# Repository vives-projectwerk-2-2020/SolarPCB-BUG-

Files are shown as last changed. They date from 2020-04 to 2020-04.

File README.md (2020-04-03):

# SolarPCB-BUG-
Full project with schematic, board and datasheets of the solar consumption board

In deze repo zit alles wat ik heb gebruikt voor mijn pcb. De schema's van ieder develop bordje en mijn eigen pcb.
Ook telkens de datasheet van mijn gebruikte IC's

## -BUG-

het probleem waar ik mee zit.
Als ik het systeem laat werken, zonder dat ik er een batterij op aansluit, is het stabiel en blijft het werken.
Vanaf ik er een batterij op aansluit, dan valt na 2 a 3 min de stroom weg en valt de laadspanning van 4,2V --> 2,7V.

De laadstroom die ik kan meten gedurdende de 2 a 3 werkende minuten is 3,7 a 3,9 mA met een laadspanning van 4,2V.

Als ik de PCB eens los maak van de zonnepanneel en terug aansluit, dan werkt de PCB terug voor enkele minuten en valt daarna terug uit.
Ook als ik de capaciteit ontlaadt, werkt het terug, maar dan kom ik gewoon terug in de start postitie te staan, waardoor het logisch is dat hij terug werkt.

Het is IC MCP73871 die uitvalt. Op zijn uitgang (Vbat) komt er dan een spanning van 2.7V en in werkende toestand staat daar een spanning van 4,2V, alle IC's erna, zijn afhankelijk van deze IC, dus de MCP73871 kan maximaal 2.7V meer leveren aan de batterij, wat te weinig is.

Eerst dacht ik dat de ingangsspanning te hoog was voor de IC, waardoor hij uitschakelde, of sneuvelde omdat mijn zonnepanneel 7V leverde en er max 6V op de ingang van de IC mocht komen. Ik heb er een 7805 tussen geplaatst, maar tevergeefs.

mochten er nog zaken niet duidelijk zijn over het probleem, mag je mij altijd een mailtje sturen, of op teams een DM sturen.

Alvast bedankt!

Tom Van Hove

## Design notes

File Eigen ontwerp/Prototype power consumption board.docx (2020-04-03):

# Prototype power consumption board

# Schematic

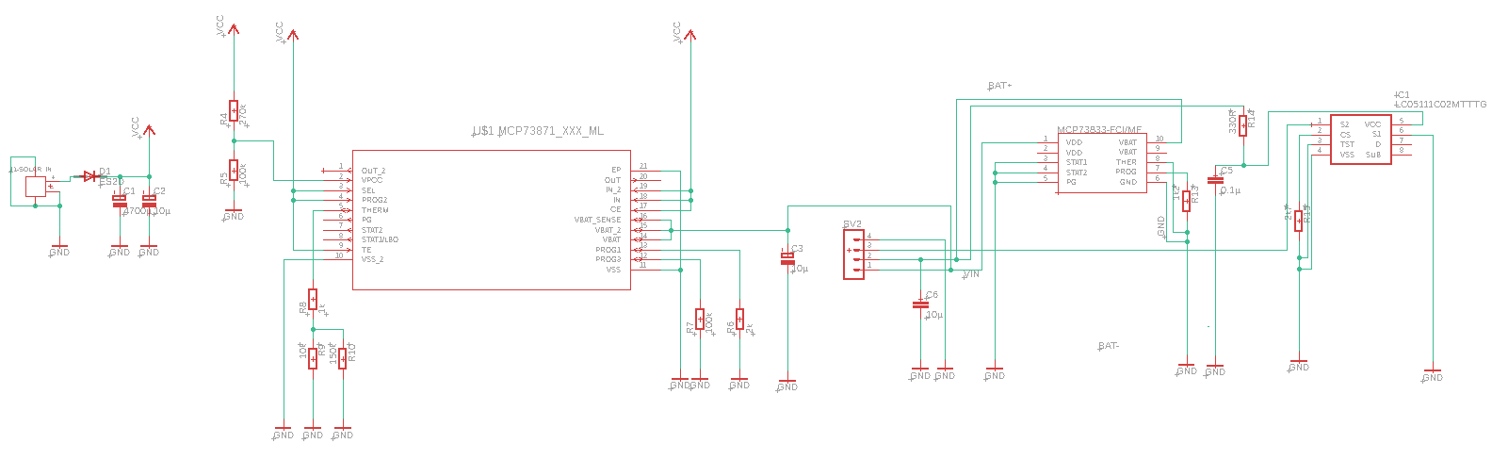
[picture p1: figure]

# Board

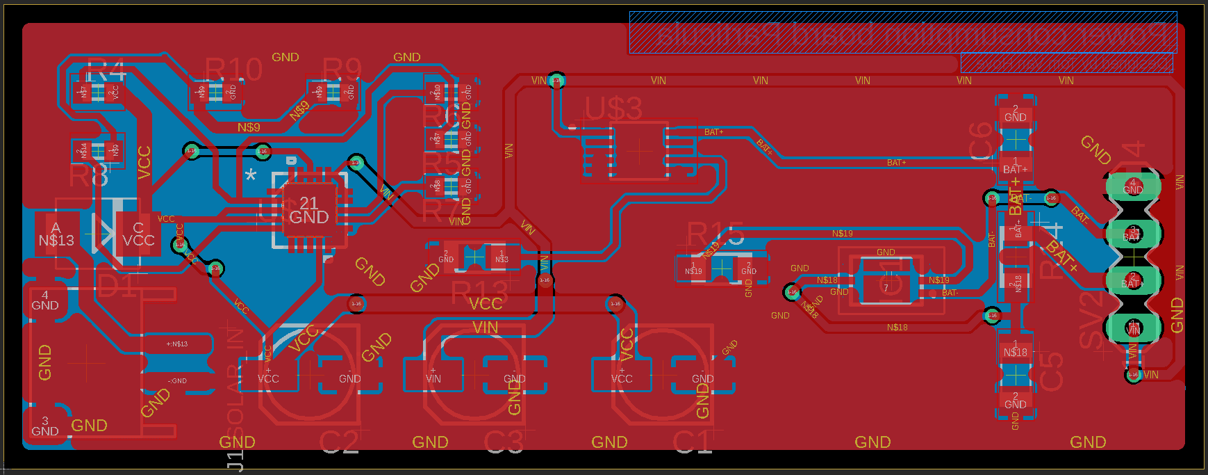
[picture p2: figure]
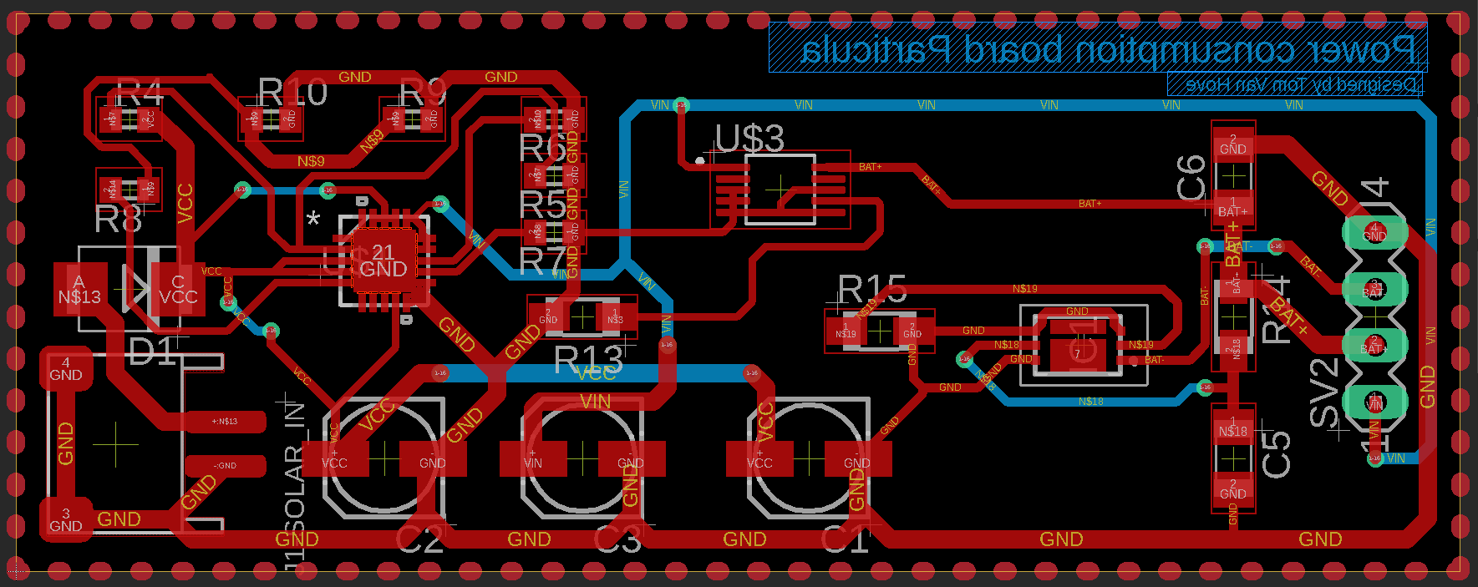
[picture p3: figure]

# Partlist FARNELL

Part | Value | FARNELL NR
C1 | 4700Âµ | 2346507
C2 | 10Âµ | 9697012
C3 | 10Âµ | 9697012
C5 | 0.1Âµ | 2211074
C6 | 10Âµ | 1907353
D1 | ES2D | 1467491
IC1 | LC05111C02MTTTG | 2728216
J1-SOLAR_IN
R4 | 270k | 2447313
R5 | 100k | 1692517
R6 | 2k | 2447319
R7 | 100k | 1692517
R8 | 1k | 9238484
R9 | 10k | 2861870
R10 | 150k | 2447254
R13 | 1k2 | 3254959
R14 | 330R | 3254970
R15 | 2k7 | 3254908
SV2 | | 1667510
U$1 | MCP73871_XXX_ML | 1642489
U$3 | MCP73833-FCI/MF | 1605576

# Recommandations

## PCB order

The ordering of the PCBs went very well. JLCPCB is an good site with fast shipping. The quality of them are very nice!

## Component order

We worked with Farnell because their fast shipping. Everything went well, all components are in stock and they were delivered very soon. But in multiple packets.

## Soldering

The soldering went great. We used only SMD. With the soldering station of VIVES it went very good! We used very small components because of available space on our PCB and we need to fit 3 PCBs in 1 single box with batteries.

I can make my PCB more smaller and that’s the next step after testing and debugging.

One mistake we made with the component order, we didn’t order an FLUX CLEANER so our PCB is a bit dirty right now. The final PCB will be clean.

## Testing

I tested the PCB only with a solarpanell and without batteries. And I got a voltage measure of 4.2V what is very nice!

After that step I loaded some batteries and the PCB stop charging when the batteries are 3.7V loaded. I’m not sure that that would be enough for feeding the NUCLEO and other hardware. Maybe I can place 2 batteries serial, but my pcb won’t work anymore. I can place them parallel too, for more capacity.

After charging the batteries, I discharged them with an ventilator (just a consumer, it could be anything). The ventilator worked 22 hours, non stop.

After this I recharged 1 battery …

TODO

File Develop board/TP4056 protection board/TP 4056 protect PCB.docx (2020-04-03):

# TP 4056 - protect PCB

# Specificaties

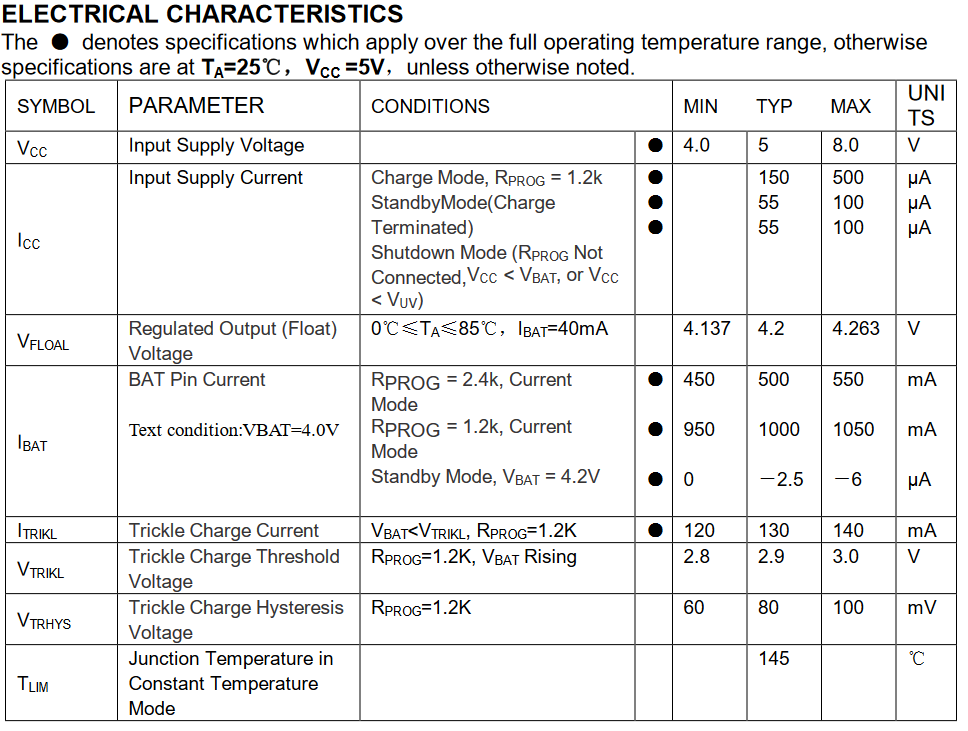
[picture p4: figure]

# Doel

Bescherming batterij tegen overspanning. Als de batterij vol geladen is, dan zal deze schakeling de kring onderbreken.

# Werking

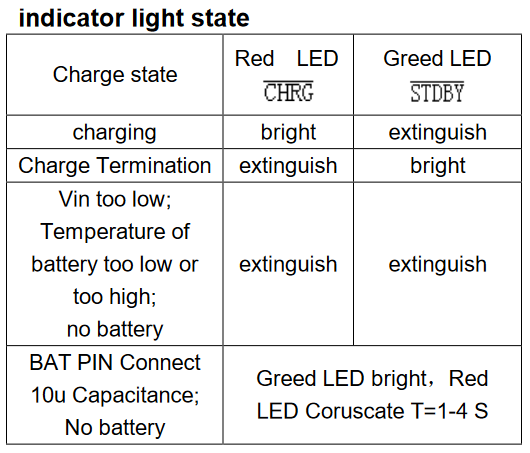
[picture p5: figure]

Als de batterij aan het opladen is, dan zal de rode led gaan branden op de PCB. Als de batterij volgeladen is dan gaat de groene led oplichten.

Stel er hangt geen batterij aan, of de ingangsspanning is te laag, temperatuur te hoog of te laag is.

Bij het opladen met het zonnepanneel, hebben we een laadstroom van rond de 50mA. Kiezen we voor een USB gevoede lading, spreken we over een laadstroom van rond de 150mA. Resultaat, via USB zal de batterij veel sneller geladen kunnen worden.

Als de spanning van de batterij stijgt, dan zal de laadstroom dalen, tot op 0, waarbij de groene led dan gaat branden.

# Schematische voorstelling

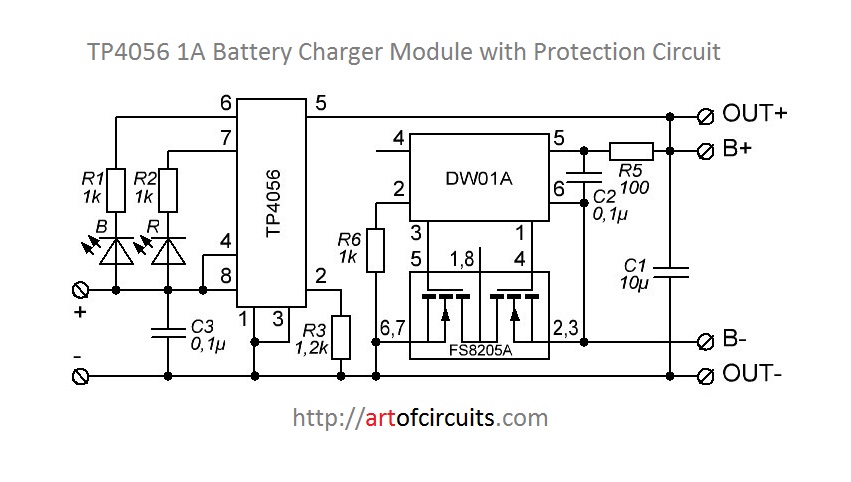
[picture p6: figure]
Schema
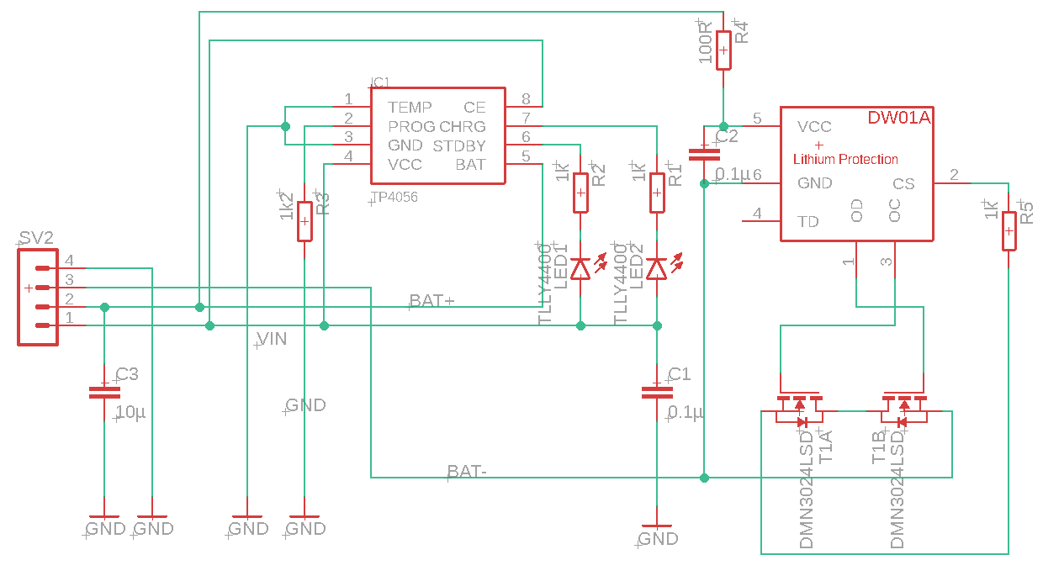
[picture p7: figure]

# Board

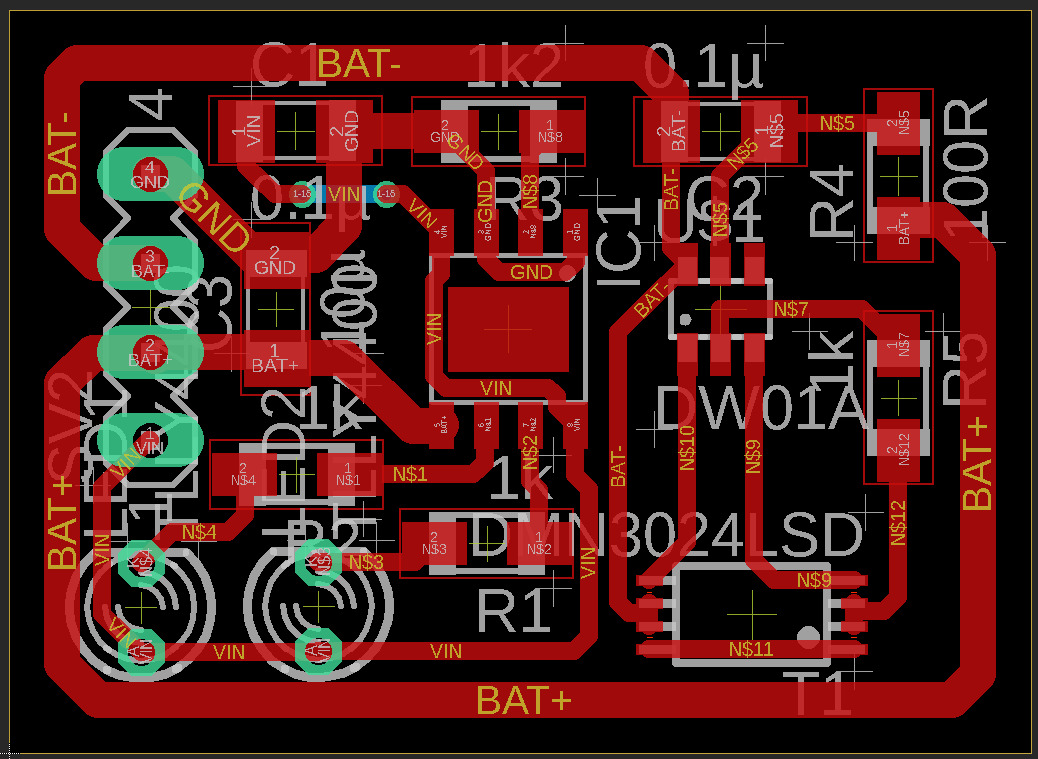
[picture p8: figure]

## DW01A

https://www.ic-fortune.com/upload/Download/DW01x-DS-17_EN_53550.pdf

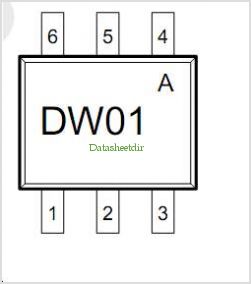
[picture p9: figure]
DW01A pinout,Pin out

## TP4056

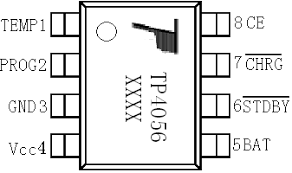
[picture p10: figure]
C:\Users\Tom\AppData\Local\Microsoft\Windows\INetCache\Content.MSO\A78E72FA.tmp

## FS8205A

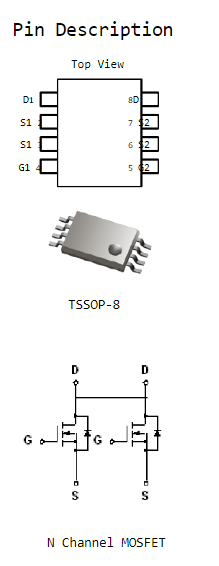
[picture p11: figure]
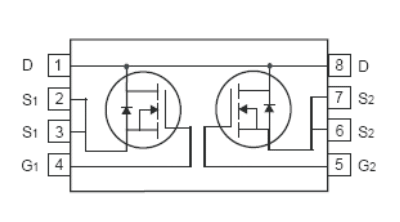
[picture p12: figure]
Afbeeldingsresultaat voor 8205a pinout
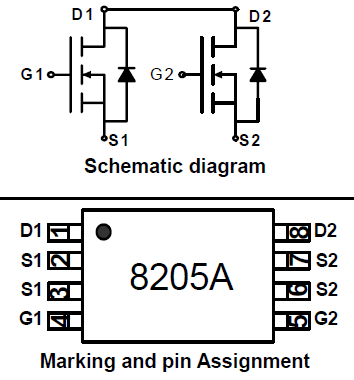
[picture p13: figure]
Afbeeldingsresultaat voor 8205a pinout

# Aansluiting

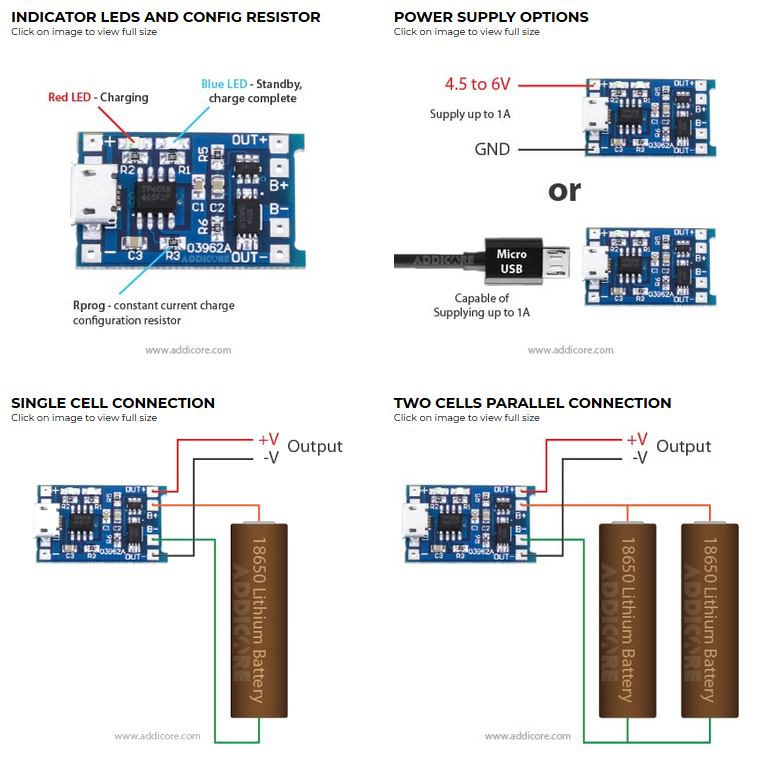
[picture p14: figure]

# Interessante links

https://dlnmh9ip6v2uc.cloudfront.net/datasheets/Prototyping/TP4056.pdf

https://www.makerlab-electronics.com/product/tp4056-5v-1a-lithium-battery-charging-with-protection-micro-usb/

https://www.addicore.com/TP4056-Charger-and-Protection-Module-p/ad310.htm

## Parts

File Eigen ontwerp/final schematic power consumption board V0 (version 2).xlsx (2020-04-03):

Part | Value | Device | Package | Description
C1 | 4700Âµ | CPOL-EU153CLV-0505 | 153CLV-0505 | POLARIZED CAPACITOR, European symbol | 2346507 | 3 | https://be.farnell.com/rubycon/16pk4700mefc12-5x25/cap-4700-f-16v-20/dp/2346507
C2 | 10Âµ | CPOL-EU153CLV-0505 | 153CLV-0505 | POLARIZED CAPACITOR, European symbol | 9697012 |  | https://be.farnell.com/panasonic/eee1va100sr/cap-10-f-35v-radial-smd/dp/9697012
C3 | 10Âµ | CPOL-EU153CLV-0505 | 153CLV-0505 | POLARIZED CAPACITOR, European symbol | 9697012 |  | https://be.farnell.com/panasonic/eee1va100sr/cap-10-f-35v-radial-smd/dp/9697012
C5 | 0.1Âµ | C-EUC1206 | C1206 | CAPACITOR, European symbol | 2211074 |  | https://be.farnell.com/tdk/cga5l2c0g1h104j160aa/cap-0-1-f-50v-5-c0g-np0-1206/dp/2211074
C6 | 10Âµ | C-EUC1206 | C1206 | CAPACITOR, European symbol | 1907353 |  | https://be.farnell.com/tdk/c3216x7r1c106k160ac/cap-10-f-16v-10-x7r-1206/dp/1907353
D1 | ES2D | ES2D | SMB | DIODE | 1467491 |  | https://be.farnell.com/on-semiconductor/es2d/diode-fast-2a-200v-smd-do-214/dp/1467491?st=ES2D
IC1 | LC05111C02MTTTG | LC05111C02MTTTG | LC05111C02MTTTG | Battery Management 1 CELL LIB PROTECTION IC | 2728216 |  | https://be.farnell.com/on-semiconductor/lc05111c02mtttg/over-current-protector-li-ion/dp/2728216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
J1-SOLAR_IN |  | CONN-HEADER-SMD-PH-SIDE-(2P-2.0MM) | HW2-SMD-2.0-90D | 320110026
R4 | 270k | R-EU_R0603 | R0603 | RESISTOR, European symbol | 2447313 |  | https://be.farnell.com/multicomp/mcwr06x2703ftl/res-270k-1-0-1w-thick-film/dp/2447313
R5 | 100k | R-EU_R0603 | R0603 | RESISTOR, European symbol | 1692517 |  | https://be.farnell.com/vishay/crcw0603100kjnea/res-100k-5-0-1w-0603-thick-film/dp/1692517
R6 | 2k | R-EU_R0603 | R0603 | RESISTOR, European symbol | 2447319 |  | https://be.farnell.com/multicomp/mcwr06x2001ftl/res-2k-1-0-1w-0603-thick-film/dp/2447319
R7 | 100k | R-EU_R0603 | R0603 | RESISTOR, European symbol | 1692517 |  | https://be.farnell.com/vishay/crcw0603100kjnea/res-100k-5-0-1w-0603-thick-film/dp/1692517
R8 | 1k | R-EU_R0603 | R0603 | RESISTOR, European symbol | 9238484 |  | https://be.farnell.com/yageo/rc0603fr-071kl/res-1k-1-0-1w-0603-thick-film/dp/9238484
R9 | 10k | R-EU_R0603 | R0603 | RESISTOR, European symbol | 2861870 |  | https://be.farnell.com/te-connectivity/crgcq0603j10k/res-10k-5-0603-thick-film/dp/2861870
R10 | 150k | R-EU_R0603 | R0603 | RESISTOR, European symbol | 2447254 |  | https://be.farnell.com/multicomp/mcwr06x1503ftl/res-150k-1-0-1w-thick-film/dp/2447254
R13 | 1k2 | R-EU_R1206W | R1206W | RESISTOR, European symbol | 3254959 |  | https://be.farnell.com/rohm/ltr18ezpj122/res-1k2-5-0-75w-1206-thick-film/dp/3254959
R14 | 330R | R-EU_R1206W | R1206W | RESISTOR, European symbol | 3254970 |  | https://be.farnell.com/rohm/ltr18ezpj331/res-330r-5-0-75w-1206-thick-film/dp/3254970
R15 | 2k7 | R-EU_R1206W | R1206W | RESISTOR, European symbol | 3254908 |  | https://be.farnell.com/rohm/ltr18ezpf2701/res-2k7-1-0-75w-1206-thick-film/dp/3254908
SV2 |  | MA04-1 | MA04-1 | PIN HEADER | 1667510 |  | https://be.farnell.com/samtec/ces-104-01-t-s/receptacle-2-54mm-single-4way/dp/1667510
U$1 | MCP73871_XXX_ML | MCP73871_XXX_ML | QFN20_4X4MC |  | 1642489 |  | https://be.farnell.com/microchip/mcp73871-2cci-ml/ic-battery-management-cont-qfn20/dp/1642489?st=MCP73871
U$3 | MCP73833-FCI/MF | MCP73833-FCI/MF | SOP50P490X110-10N |  | 1605576 |  | https://be.farnell.com/microchip/mcp73833-fci-un/ic-charge-control-li-ion-1a-msop/dp/1605576?st=MCP73833

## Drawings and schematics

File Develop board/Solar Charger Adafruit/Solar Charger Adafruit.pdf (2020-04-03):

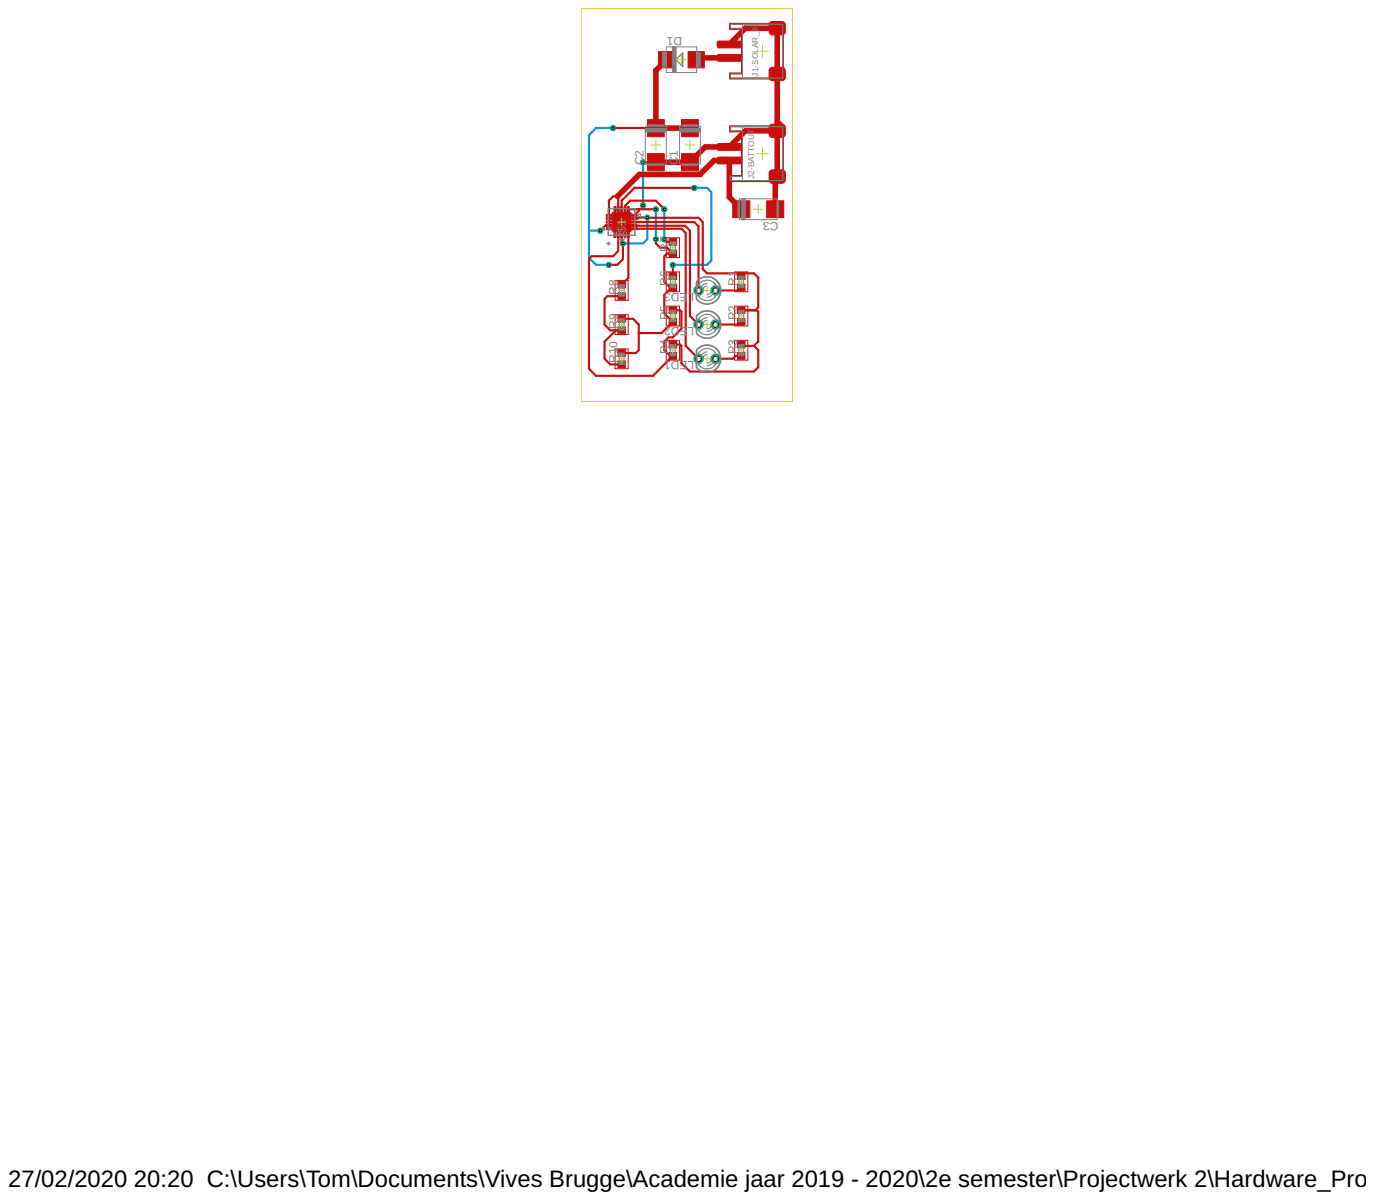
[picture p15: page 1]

27/02/2020 20:20 C:\Users\Tom\Documents\Vives Brugge\Academie jaar 2019 - 2020\2e semester\Projectwerk 2\Hardware_Prototype\Solar Charger Adafruit\Solar Charger Adafruit.brd

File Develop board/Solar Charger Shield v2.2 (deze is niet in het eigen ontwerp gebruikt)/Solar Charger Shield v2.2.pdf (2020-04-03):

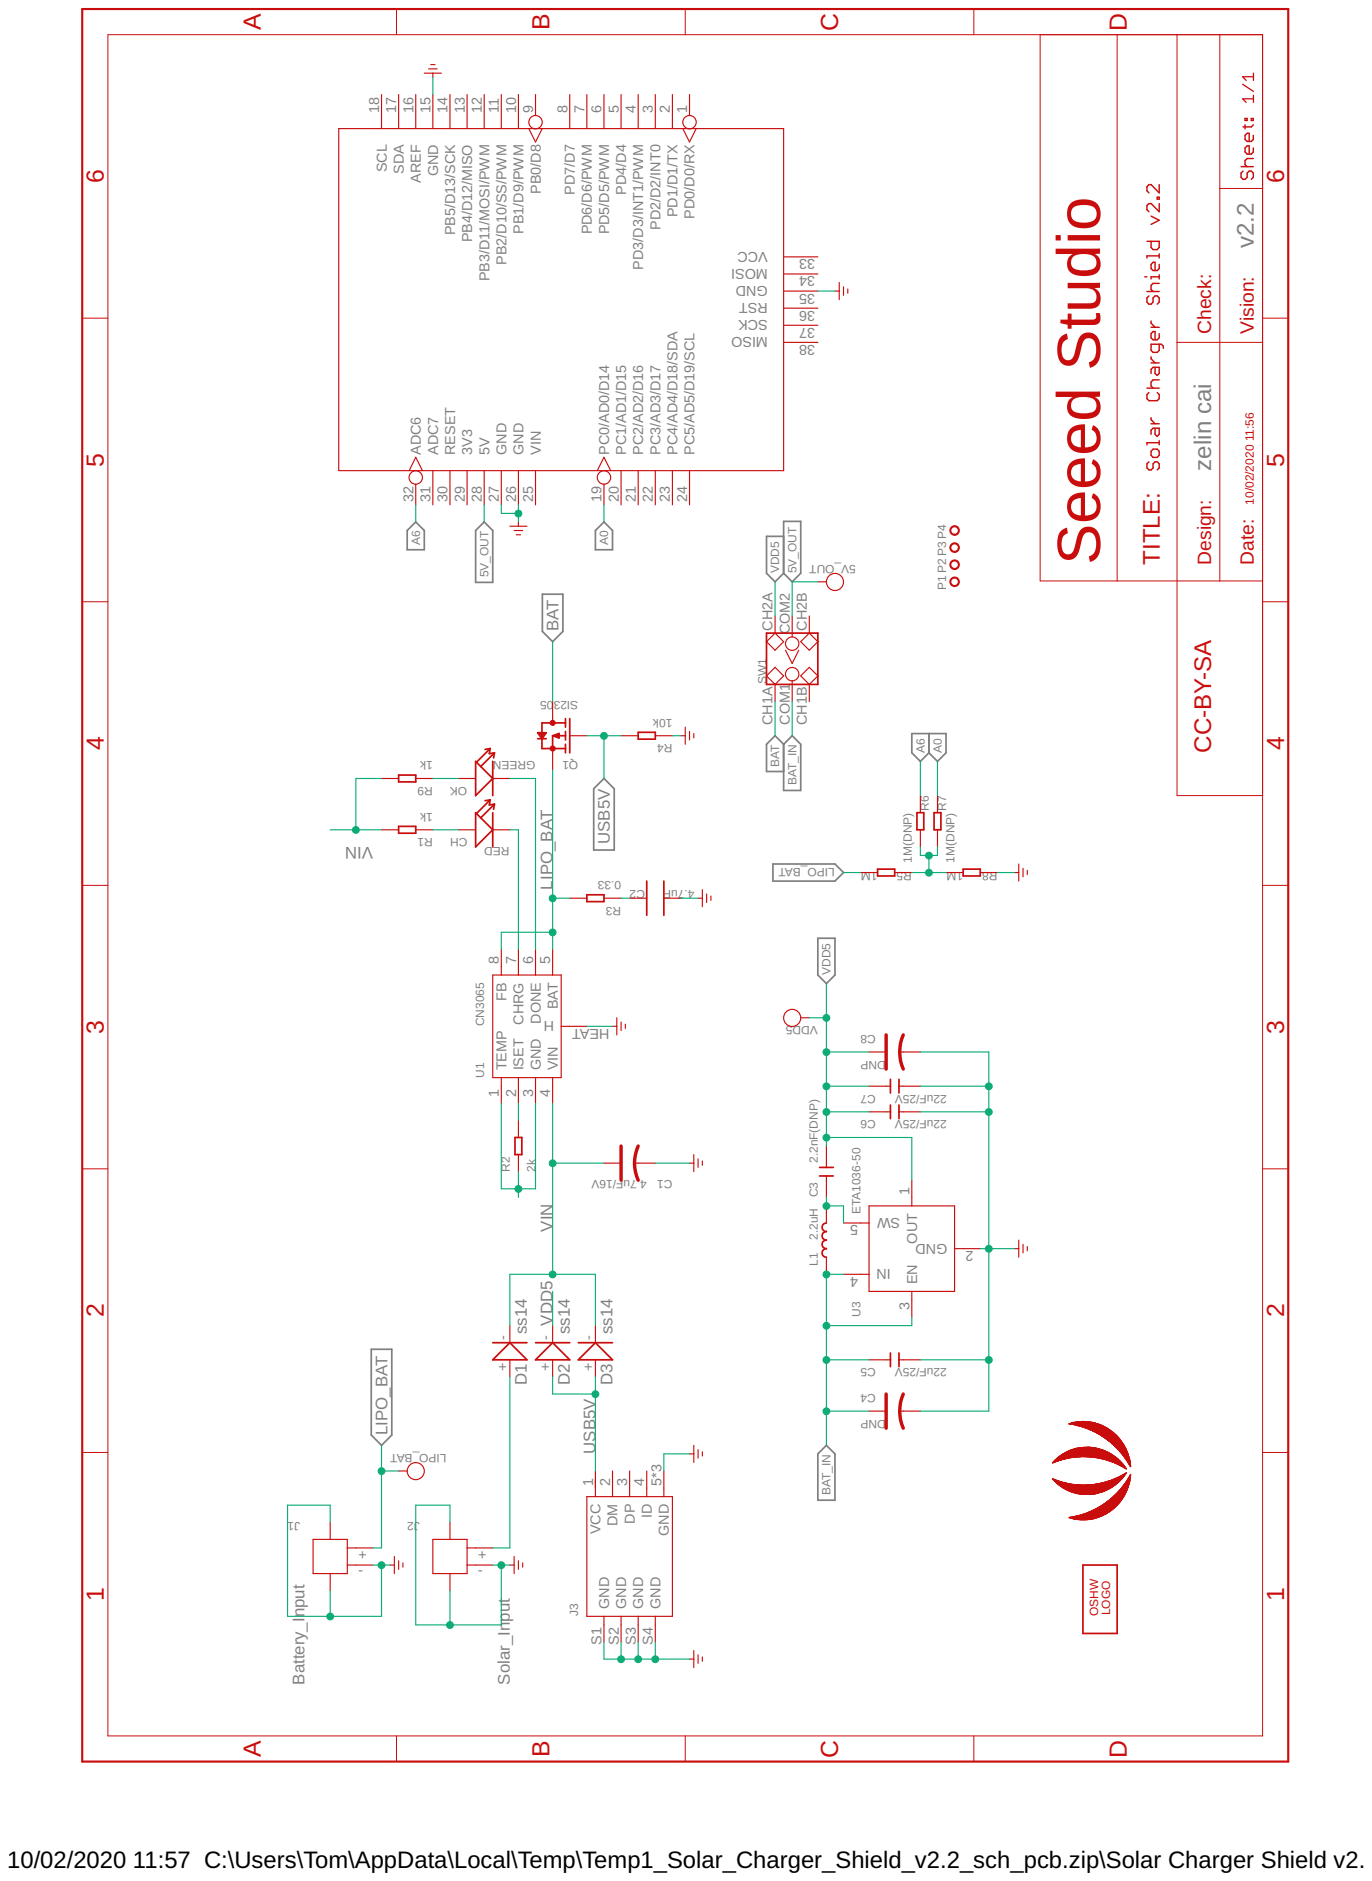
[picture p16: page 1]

TITLE: Design: Check: Date: Vision:

10/02/2020 11:57 C:\Users\Tom\AppData\Local\Temp\Temp1_Solar_Charger_Shield_v2.2_sch_pcb.zip\Solar Charger Shield v2.2.sch (Sheet: 1/1)

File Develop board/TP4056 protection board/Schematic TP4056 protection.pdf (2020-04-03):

# U3Vout 2

TP4056+protection | blob:https://easyeda.com/caab3f5a-f87a-41e1-b9f1-f607f42ea68e

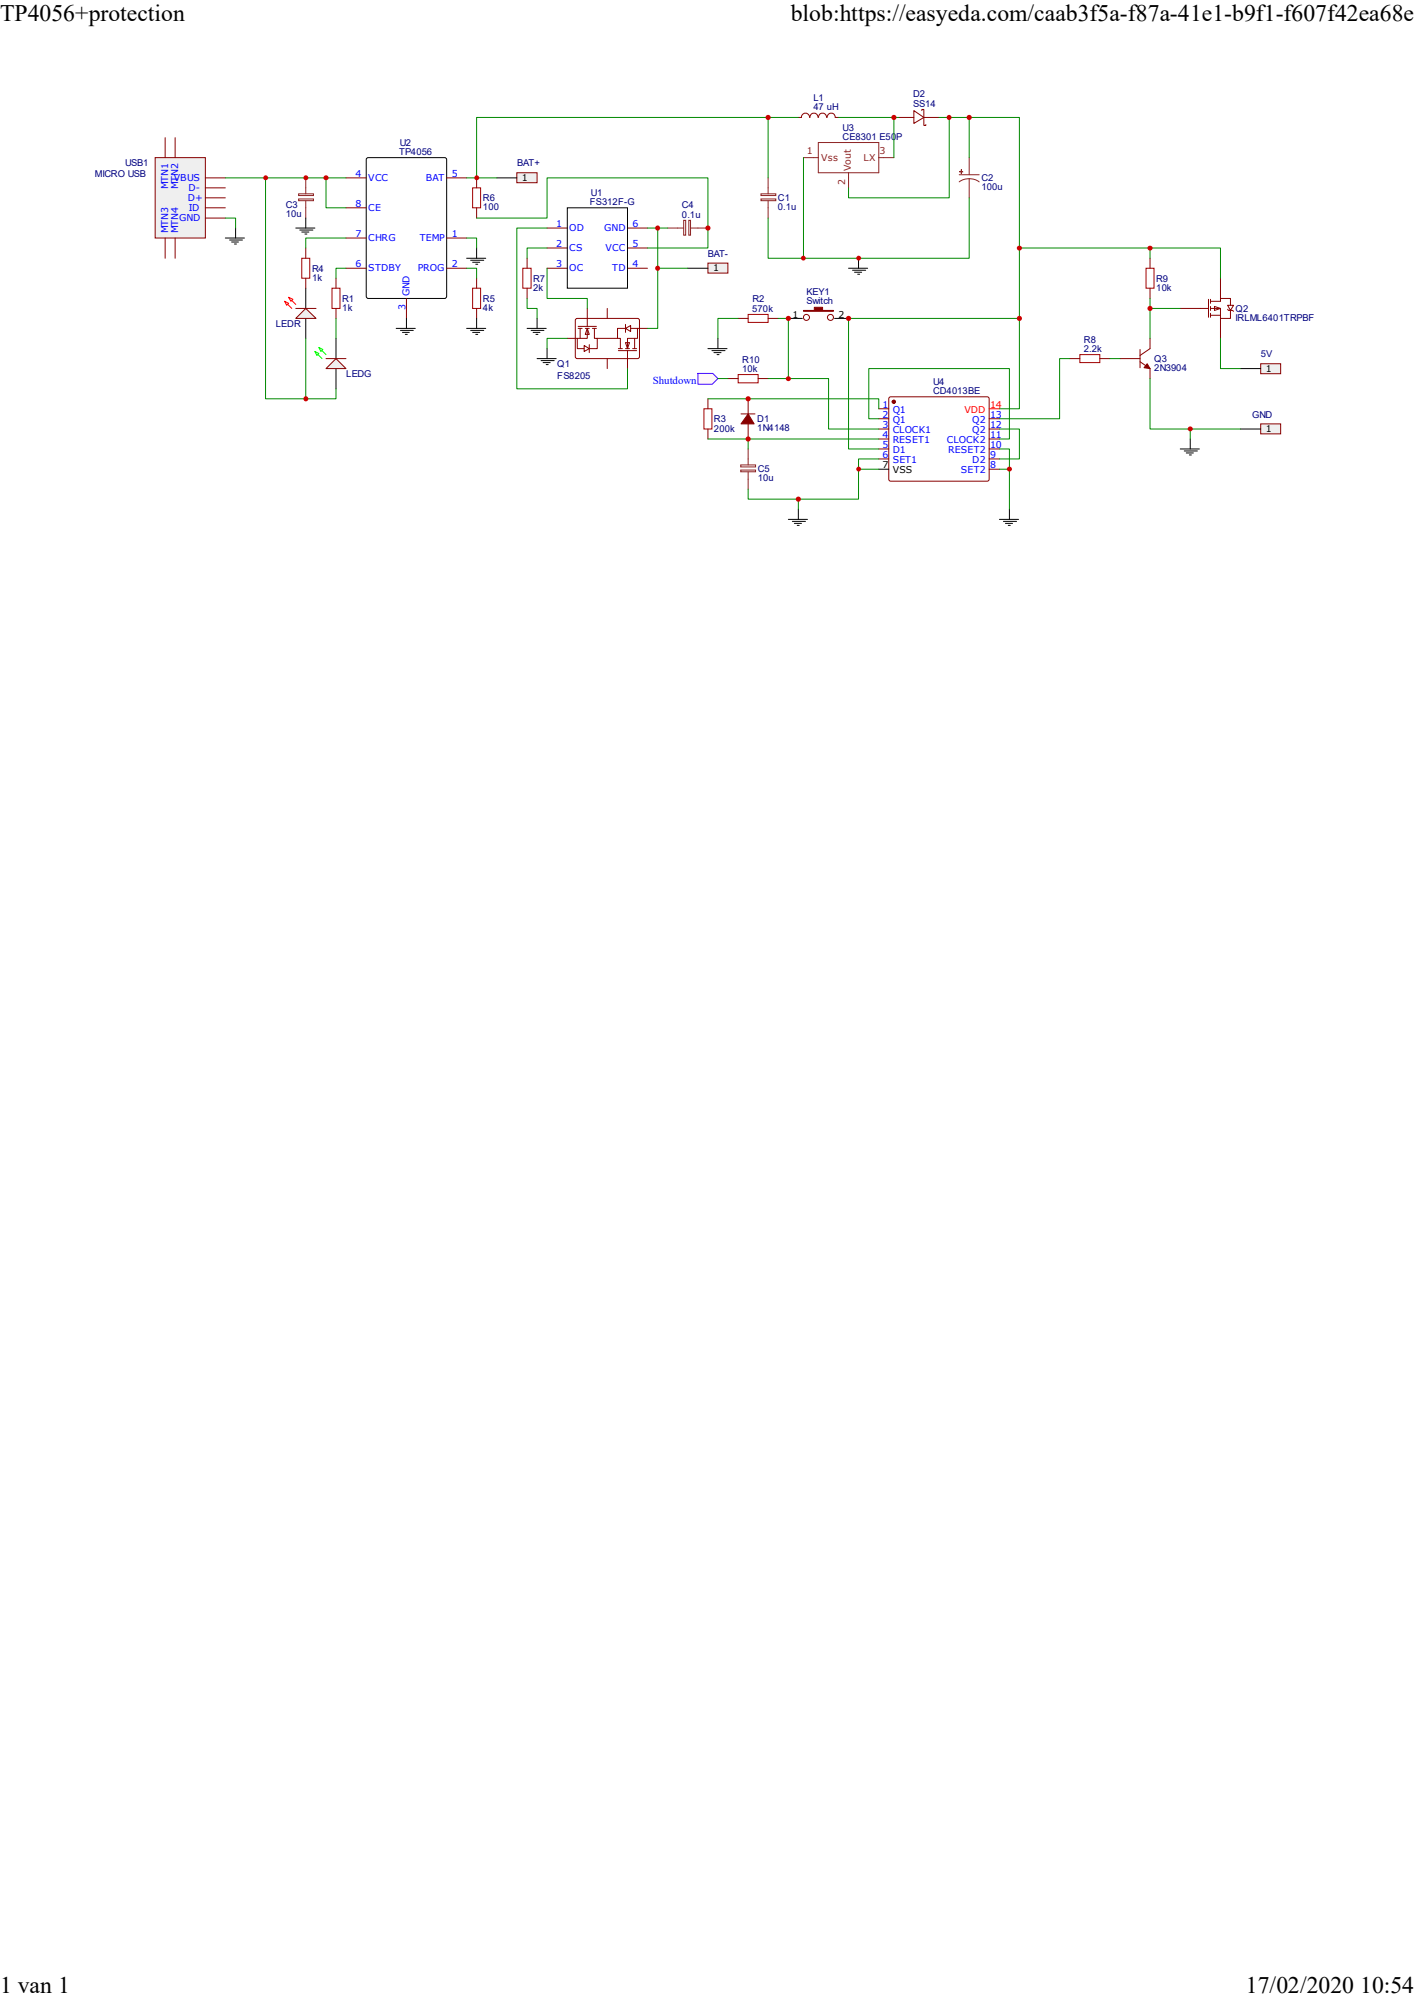
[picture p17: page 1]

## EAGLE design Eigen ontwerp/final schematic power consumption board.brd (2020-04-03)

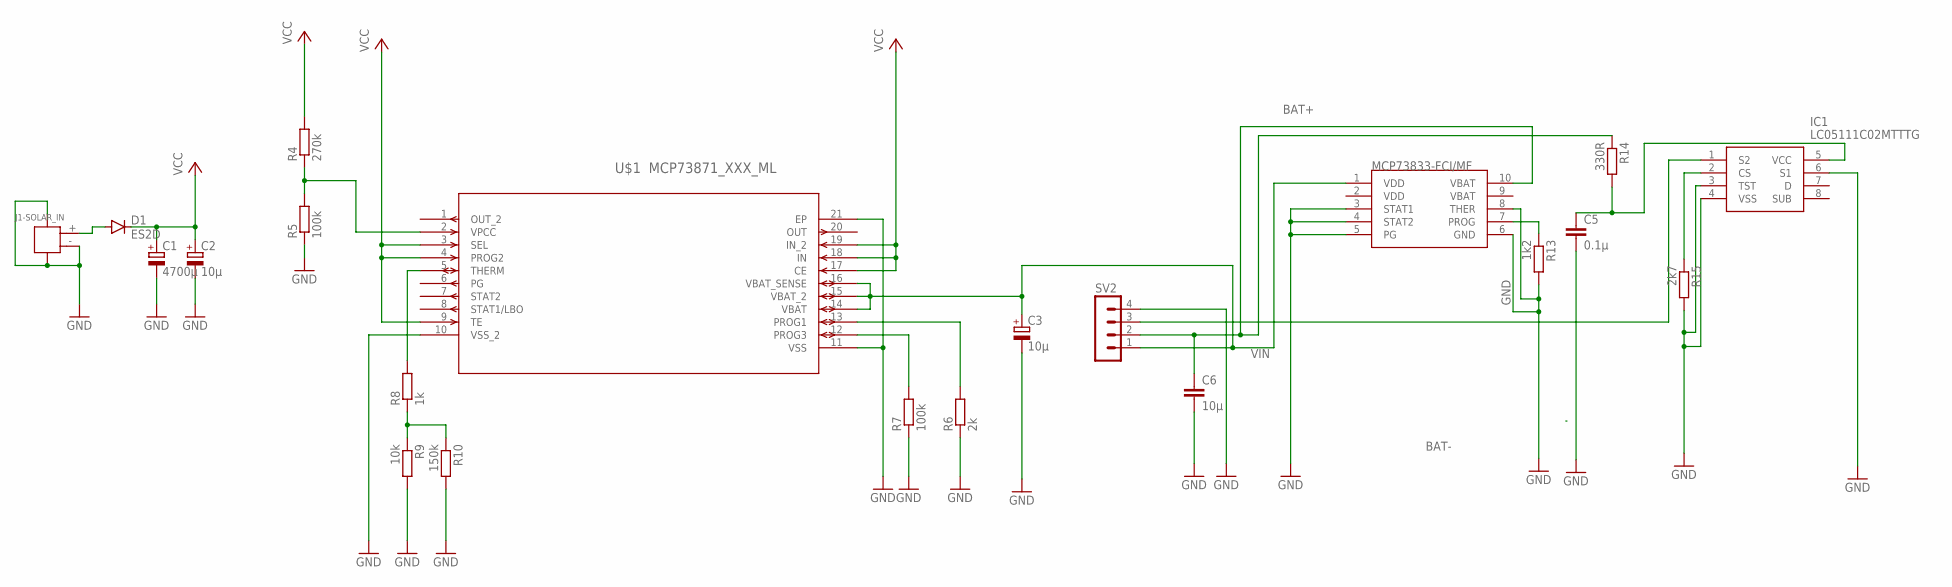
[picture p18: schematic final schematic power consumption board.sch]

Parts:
C1: 4700µ; 153CLV-0505
C2, C3: 10µ; 153CLV-0505
C5: 0.1µ; C1206
C6: 10µ; C1206
D1: ES2D; SMB
IC1: LC05111C02MTTTG
J1-SOLAR_IN: CONN-HEADER-SMD-PH-SIDE-(2P-2.0MM); HW2-SMD-2.0-90D
R4: 270k; R0603
R5, R7: 100k; R0603
R6: 2k; R0603
R8: 1k; R0603
R9: 10k; R0603
R10: 150k; R0603
R13: 1k2; R1206W
R14: 330R; R1206W
R15: 2k7; R1206W
SV2: MA04-1
U$1: MCP73871_XXX_ML; QFN20_4X4MC
U$3: MCP73833-FCI/MF; SOP50P490X110-10N

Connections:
BAT+: C6.1, R14.1, SV2.2, U$3.10 (VBAT)
BAT-: IC1.1 (S2), SV2.3
GND: C1.-, C2.-, C3.-, C5.2, C6.2, IC1.3 (TST), IC1.4 (VSS), IC1.6 (S1), J1-SOLAR_IN.3, J1-SOLAR_IN.4, J1-SOLAR_IN.- (2), R5.1, R6.1, R7.1, R9.2, R10.2, R13.2, R15.2, SV2.4, U$1.10 (VSS_2), U$1.11 (VSS), U$1.21 (EP), U$3.3 (STAT1), U$3.4 (STAT2), U$3.5 (PG), U$3.6 (GND), U$3.8 (THER)
unnamed: R13.1, U$3.7 (PROG)
unnamed: R4.1, R5.2, U$1.2 (VPCC)
unnamed: R7.2, U$1.12 (PROG3)
unnamed: R8.1, R9.1, R10.1
unnamed: R6.2, U$1.13 (PROG1)
unnamed: D1.A, J1-SOLAR_IN.+ (1)
unnamed: R8.2, U$1.5 (THERM)
unnamed: C5.1, IC1.5 (VCC), R14.2
unnamed: IC1.2 (CS), R15.1
VCC: C1.+, C2.+, D1.C, R4.2, U$1.3 (SEL), U$1.4 (PROG2), U$1.9 (TE), U$1.17 (CE), U$1.18 (IN), U$1.19 (IN_2)
VIN: C3.+, SV2.1, U$1.14 (VBAT), U$1.15 (VBAT_2), U$1.16 (VBAT_SENSE), U$3.1 (VDD)

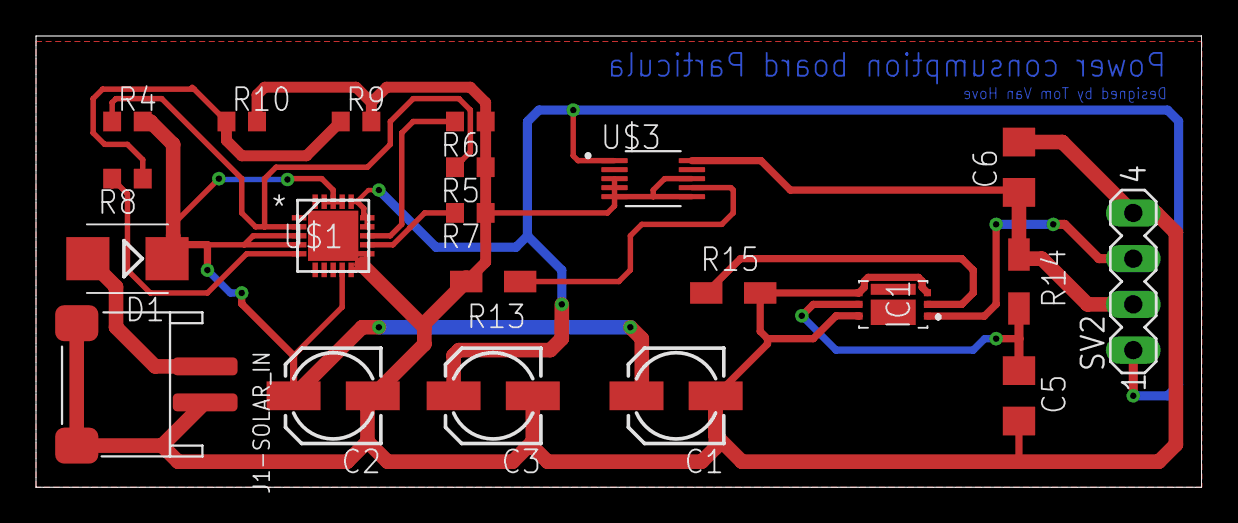
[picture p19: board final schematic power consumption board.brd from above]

Board: 2 copper layers, 64.8 x 25.1 mm, 21 parts (0 on the bottom side), 14 nets.

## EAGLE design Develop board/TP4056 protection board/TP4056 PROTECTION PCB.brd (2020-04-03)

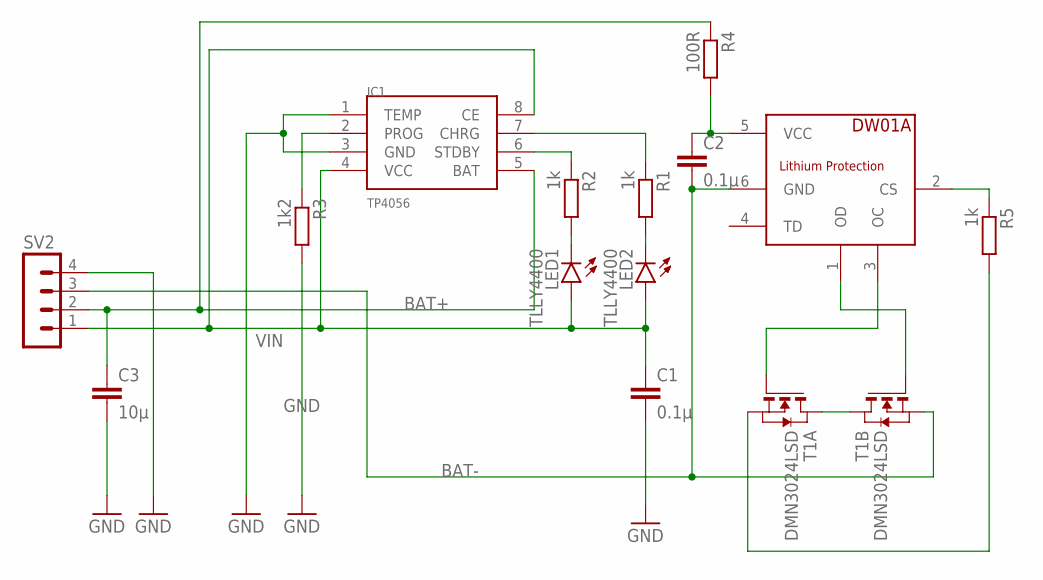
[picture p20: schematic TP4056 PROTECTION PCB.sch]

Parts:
C1, C2: 0.1µ; C1206
C3: 10µ; C1206
IC1: TP4056; SOP-8
LED1, LED2: TLLY4400; LED3MM
R1, R2, R5: 1k; R1206W
R3: 1k2; R1206W
R4: 100R; R1206W
SV2: MA04-1
T1: DMN3024LSD; TSSOP-8
U$1: DW01A; SOT23-6

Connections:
BAT+: C3.1, IC1.5 (BAT), R4.1, SV2.2
BAT-: C2.2, SV2.3, T1.6 (S), T1.7 (S), U$1.6 (GND)
GND: C1.2, C3.2, IC1.1 (TEMP), IC1.3 (GND), R3.2, SV2.4
unnamed: IC1.6 (STDBY), R2.1
unnamed: IC1.7 (CHRG), R1.1
unnamed: LED2.K (C), R1.2
unnamed: LED1.K (C), R2.2
unnamed: C2.1, R4.2, U$1.5 (VCC)
unnamed: R5.1, U$1.2 (CS)
unnamed: IC1.2 (PROG), R3.1
unnamed: T1.4 (G), U$1.3 (OC)
unnamed: T1.5 (G), U$1.1 (OD)
unnamed: T1.1 (D), T1.8 (D)
unnamed: R5.2, T1.2 (S), T1.3 (S)
VIN: C1.1, IC1.4 (VCC), IC1.8 (CE), LED1.A, LED2.A, SV2.1

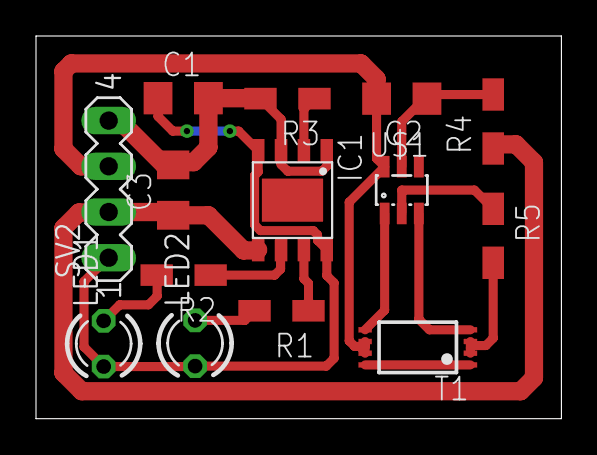
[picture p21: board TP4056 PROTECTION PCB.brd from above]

Board: 2 copper layers, 29.2 x 21.3 mm, 14 parts (0 on the bottom side), 15 nets.

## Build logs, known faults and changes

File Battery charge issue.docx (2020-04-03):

# Battery charge issue

# 17/02/2020

Opzetten van een prototype om een batterij op te laden.

De uitgangsspanning van het beschermings printje, is 4v2. Onze spanning van de batterij is 3v7.

Het protect printje gaat uitschakelen zodra de batterij is opgeladen, dit is visueel zichtbaar door de groene led die gaat oplichten.

Als de batterij nog aan het opladen is, dan brandt het rode ledje.

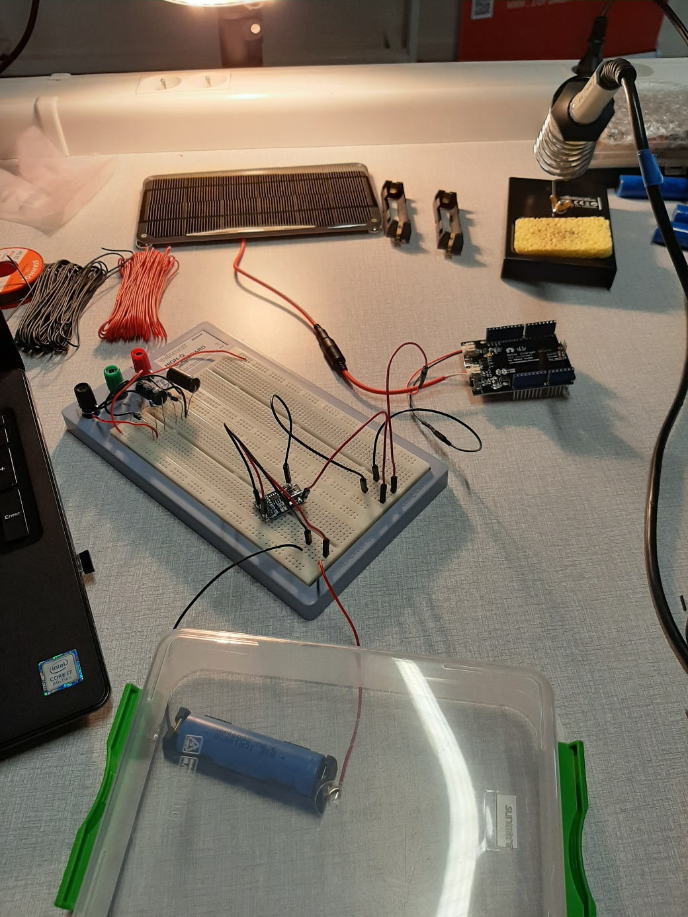
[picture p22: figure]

Bij het meten van de laadstroom, meet ik een stroom van 50mADC
